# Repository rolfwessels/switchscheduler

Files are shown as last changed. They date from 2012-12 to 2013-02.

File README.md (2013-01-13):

Switch Scheduler
===============

Remotely schedule a switch to go on and off

The Idea
============
The idea is to have a web server host some scheduling setting. Then I would have an arduino with a wifly connected poll for new setting every 10 minutes. Based on the schedule I want to switch 1 or more switches on and off.

The story
==============
Initially I wanted this schedule to run for my geyser. Obviously a geyser pulls a lot of current and I was scared to tinker with a relay, so the plan was to switch it on and off using a servo and a little printed part. This would work on a normal switch but unfortunately this switch requires too much force for my servo. 

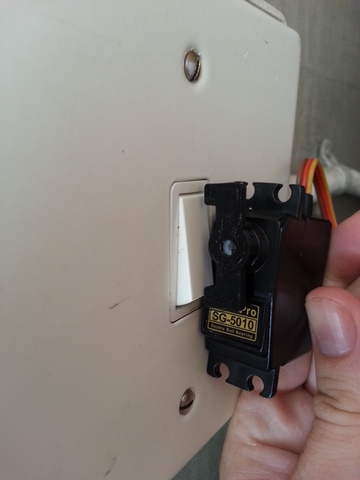
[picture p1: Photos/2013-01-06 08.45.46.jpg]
3d printed part to toggle the switch


Next would be to do it the right way using a relay. I went to my local electronic shop and picked up a hf18ff relay. It is a 12v relay and the arduino pins only push out 5v so I need to up the voltage somehow.

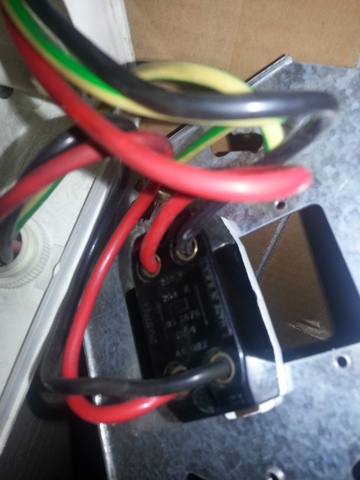
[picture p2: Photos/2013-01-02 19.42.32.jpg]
The back of the switch that will be hacked

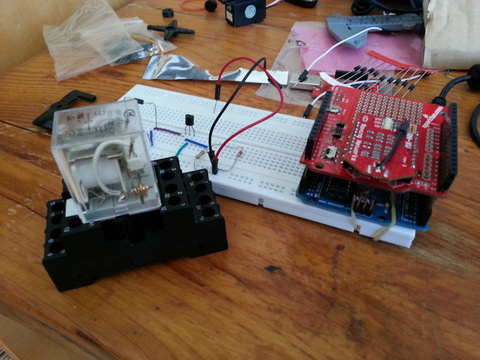
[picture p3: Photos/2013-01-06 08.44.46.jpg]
The relay and the wifly

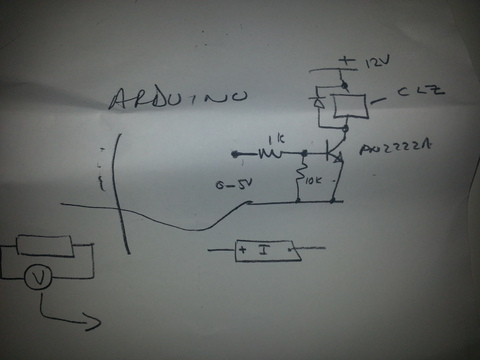
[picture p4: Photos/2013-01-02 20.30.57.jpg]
The suggested way of getting 5v to 12v


Missing bits
=============

- Develop the scheduling server
- Updating fritzing file
- Togle the 12v relay
- Installing the relay
- Create instructable
- Store schedule file on sd card for offline scheduling

Component list
===============

- arduino uno
- wifly
- wifly breakout board
- Relay [hf18ff]
- diode [1n4007]
- 1k resistor (R1)
- 10k resistor (R2)
- transistor [pn2222A]
- power supply (12V)

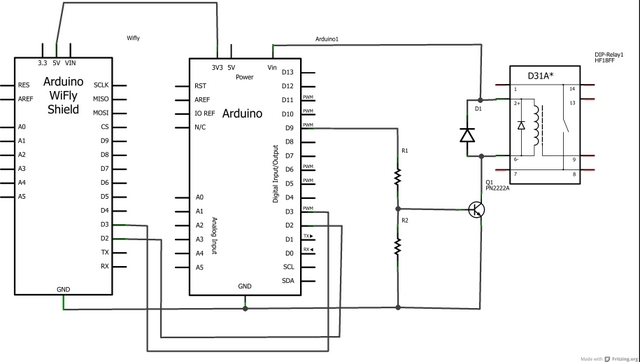
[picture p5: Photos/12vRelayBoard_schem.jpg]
The circuit


Required Arduino libraries
==============================

The schedular makes use of the following libraries. These libraries are included in the source code.
```AJson
NewSoftSerial
PString
SoftwareServo
Streaming
Time
TimeAlarms
WiFlySerial
```
All the arduino code is stored in folder ArduinoRemoteSwitch

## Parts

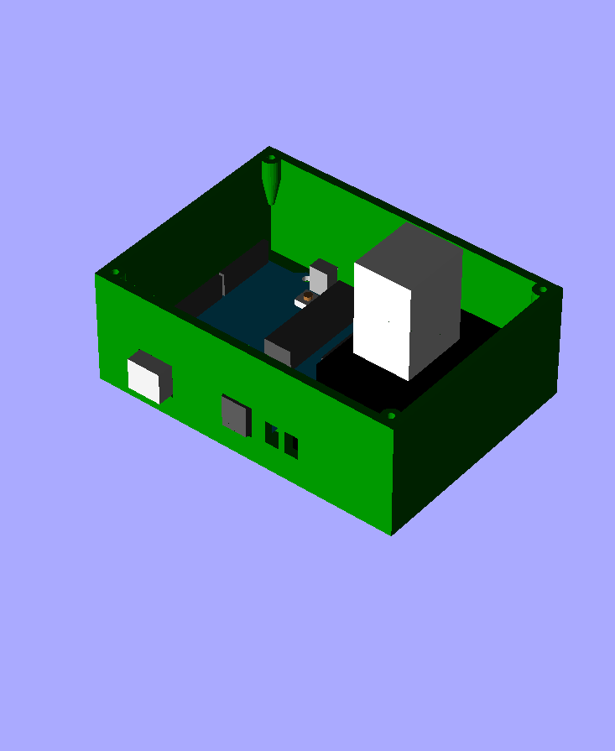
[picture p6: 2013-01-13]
Photos/boxWithComponents.png

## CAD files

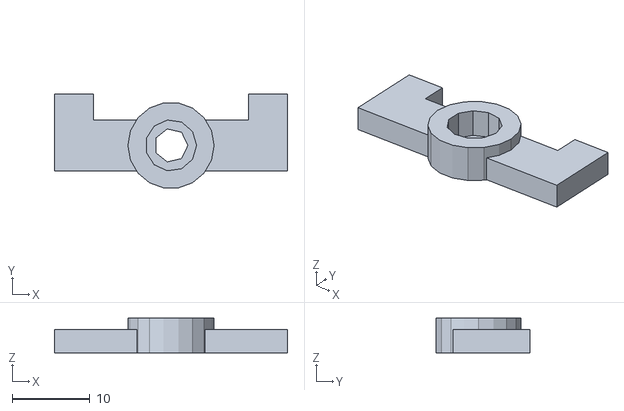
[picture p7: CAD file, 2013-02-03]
3dPrintedParts/ServoArm.stl
30.0 x 12.1 x 4.50

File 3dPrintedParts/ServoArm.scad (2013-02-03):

module cilinder()
{
	depth = 4.5;
	diameter = 3.2;
	dw = depth/2;
	dwI = dw/2;

	armDepth = depth/1.5;
	armHeigth = 18;
	armWidth = (diameter)*2;


	armGripsWidth = 5;
	armGripsHeigth = armWidth*1.5;

	difference() {
		union() {
			translate([-armHeigth/2,-armWidth/2,0])
     			cube([armHeigth,armWidth,armDepth]);
			translate([-armHeigth/2-armGripsWidth,-armWidth/2,0])
				cube([armGripsWidth,armGripsHeigth,armDepth]);
			translate([armHeigth/2,-armWidth/2,0])
				cube([armGripsWidth,armGripsHeigth,armDepth]);
			cylinder(depth,diameter+dw,diameter+dw);

			translate([-15,-armWidth/2,0])
				cube([armGripsWidth,armGripsHeigth,armDepth]);
			translate([+10,-armWidth/2,0])
				cube([armGripsWidth,armGripsHeigth,armDepth]);
		}
		translate([0,0,dwI])
			cylinder(depth,diameter,diameter);
		translate([0,0,-0.1])
		cylinder(depth,diameter-dwI,diameter-dwI);
	}
	
	
}

cilinder();

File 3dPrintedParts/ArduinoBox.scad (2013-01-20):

include<arduino.scad>

module Relay()
{
	width = 24;
	height = 20;
	depth = 33;
	color("white")		
		cube([width,height,depth]);
}

module RelayAndBase()
{
	width = 67;
	height = 30;
	depth = 20;
	level0w = 38;
	level0d = 4;
	level1w = 45;
	level1d = 10;
	screwRad = 2/2;
	
	union() {
		//the black bottom
		color("black")
		difference() {
			union() {
				cube([width,height,depth]);
				translate([(width-level1w)/2,0,depth])
					cube([level1w,height,level1d]);
				
			}
			//bottom gap
			translate([(width-level0w)/2,0,0])
					cube([level0w,height,level0d]);
			//screw holes
			translate([width/2,3,0])
				cylinder(r=screwRad, h=depth+level1d+1, $fn=25);
			translate([width/2,height-3,0])
				cylinder(r=screwRad, h=depth+level1d+1, $fn=25);

		}
		//the replay
		
		translate([(width-24)/2,5,depth+level1d])
			Relay();
	}
}

module OtherElements()
{
	translate(relayOffset)
		RelayAndBase();
	translate(arduinoOffset)
		Arduino(0, 0, 0);

}

module ScrewHolder() {
	arduinoRad = 1.2;
	outer = 2;
	depth = 7;
	difference() {
		cylinder(r=arduinoRad+outer, h=depth, $fn=25);
		cylinder(r=arduinoRad, h=depth+1, $fn=25);
	}
}

module BoxScrewHoldes()
{
	down = -1*arduinoOffsetY;
	left = 67/2;
	
		translate(relayOffset)
		union() {
			
			translate([left,13,0])
				ScrewHolder();
			translate([left,37,0])
				ScrewHolder();
		}
		
		//arduino
		translate(arduinoOffset) // from other elements
		union() {
			
			translate([-1,-38.4,down])
				ScrewHolder();
			translate([0,10,down])
				ScrewHolder();
			translate([51,-33.3,down])
				ScrewHolde();
			translate([51,-5.2,down])
				ScrewHolder();
			translate([51,-33.2,down])
				ScrewHolder();
			
		}
	
		
}
module ScrewHolderAndTaper() {
	
	depth = 7;
	mod = 1.5;
	union() {
		ScrewHolder();
		translate([0,0,-depth*mod])
		cylinder(r2=3.2, h=depth*mod, $fn=25);
		
	}
}

module BoxBottom()
{
	width = boxSize[0];
	height = boxSize[1];
	depth = boxSize[2];

	difference() {
		cube(boxSize);
		translate([boxWidth,boxWidth,boxWidth])
			cube([width-(boxWidth*2),height-(boxWidth*2),depth-boxWidth+10]);
		}
	offset = boxWidth+1.2;
	depthSc = depth-7;
	translate([offset,offset,depthSc])
		ScrewHolderAndTaper();
	translate([width-offset,offset,depthSc])
		ScrewHolderAndTaper();
	translate([offset,height-offset,depthSc])
		ScrewHolderAndTaper();
	translate([width-offset,height-offset,depthSc])
		ScrewHolderAndTaper();
	
}

module PowerHoles()
{
	translate(arduinoOffset) // from other elements
	union() {
		//usb
		translate([-23,-9,3]) cube([15,13,12]);
		//power
		translate([-23,-39,4]) cube([15,11,11]);

		//power
		translate([-23,-39,4]) cube([15,8,11]);
	}
	powercableHole = [15,5,8];		
	translate(relayOffset)
	union() {
		//power
		translate([-10,41,10]) cube(powercableHole);
		translate([-10,34,10]) cube(powercableHole);
	}
	
}
module BoxTopScrewHoles()
{
	width = boxSize[0];
	height = boxSize[1];
	depth = 0;

	offset = boxWidth+1.2;
	depthSc = depth;
	myheight = boxWidth*2;
	mod = 1;

	translate([offset,offset,depthSc])
		cylinder(r=1.2, h=myheight, $fn=25);
	translate([width-offset,offset,depthSc])
		cylinder(r=1.2, h=myheight, $fn=25);
	translate([offset,height-offset,depthSc])
		cylinder(r=1.2, h=myheight, $fn=25);
	translate([width-offset,height-offset,depthSc])
		cylinder(r=1.2, h=myheight, $fn=25);
}
module BoxTop()
{
	width = boxSize[0];
	height = boxSize[1];
	depth = 0;
	difference() {
		translate([0,0,depth])
			cube([width,height,boxWidth]);
		translate([26,14,depth])
			cube([26,23,33]);
		BoxTopScrewHoles();
	}
	
	
}


module Box() {
	depth = boxSize[2];
	color("green") BoxScrewHoldes();
	difference() {
		color("green") BoxBottom();
		color("green") PowerHoles();
	}
	translate([0,0,depth+1]) color("lightgreen") BoxTop();

}

module FullBoxWithComponents() {
	translate([0,10,2]) OtherElements();
	Box();
}

module BoxBottomOnly() {
	color("green") BoxScrewHoldes();
	difference() {
		color("green") BoxBottom();
		color("green") PowerHoles();
	}
}

module TopOnly() {
	 color("lightgreen") BoxTop();
}

//Main settings
relayOffset = [5,0,0];
arduinoOffsetY = 5;
arduinoOffset = [16,90,arduinoOffsetY];
boxSize = [80,110,40];
boxWidth = 2;

// Preview
FullBoxWithComponents();

// Print 1
// BoxBottomOnly();

// Print 2
// TopOnly();

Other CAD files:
3dPrintedParts/arduino.scad
3dPrintedParts/ServoArm.skp

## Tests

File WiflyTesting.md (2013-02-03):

How to test your wifly connection using USB
==================================================
Connect to the wifly to USD
Telnet to the wifly:
Send commands:

```
$$$  //Responds with CMD
scan 30 // scans for networks
join # 3        // Join the third network

// Below sets the auth to | WPA1 | channel 11 | password XXXXXXX | join on connection | ssid | joins pings and saves connection
set wlan auth 3
set wlan channel 11 
set wlan pass XXXXXXX  

set wlan join 1
set wlan ssid CC902
join CC902
ping 74.125.233.5 2
save
reboot

set time address 129.6.15.28 
set time zone 22
set time enable 1 
time
show time
save
reboot
```

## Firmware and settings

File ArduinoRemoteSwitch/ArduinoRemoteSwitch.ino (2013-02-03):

#include <Arduino.h> 
#include <Time.h>
#include <SoftwareSerial.h>
#include <Streaming.h>
#include <PString.h>
#include <WiFlySerial.h>
#include <String.h>
#include "MemoryFree.h"
#include "Credentials.h"

#define REQUEST_BUFFER_SIZE 150
#define HTTP_RESPONSE_BUFFER_SIZE 200

#define DAYS 7
#define SCHEDULEBLOCKS 24
#define HOURFALSE 255
//time in minutes
#define SHEDULE_DOWNLOAD_SCHEDULE 10
//time in seconds
#define SHEDULE_CHECK_SCHEDULE 5 
//time in hours
#define SHEDULE_SETTIME 2

#define SettingsFullUrl "https://dl.dropbox.com/u/1343111/ServerTimer/autoSwitchSettings.txt"
#define SETTINGS_HOST "dl.dropbox.com"
//#define SETTINGS_HOST "23.21.195.136"
#define SettingsUrl "/u/1343111/ServerTimer/autoSwitchSettings.txt"


char bufRequest[REQUEST_BUFFER_SIZE];
char bufResponse[HTTP_RESPONSE_BUFFER_SIZE];

bool _daysSchedule[DAYS*SCHEDULEBLOCKS] = {false};
bool _servoState = false;
byte _onHour = HOURFALSE;
String _mac; 

bool isFirstRun = true;
int pinLed = 5;
int pinRelay = 4;
// Arduino       _wiflySerial
//  2 - receive  TX   (Send from _wiflySerial, Receive to Arduino)
//  3 - send     RX   (Send from Arduino, Receive to _wiflySerial) 
WiFlySerial _wiflySerial(2,3); 
char chOut; 


// the setup routine runs once when you press reset:
void setup() {
	Serial.begin(9600);
	pinMode(pinLed, OUTPUT);
	pinMode(pinRelay, OUTPUT);
	switchRelay(false);
	Serial << "--------------------------------------------- " <<  F("Free memory:") << freeMemory() << endl;
}


// the loop routine runs over and over again forever:
void loop() {
  while(_wiflySerial.available() > 0) {
    Serial.write(_wiflySerial.read());
  }  
  if(Serial.available()) { // Outgoing data
    _wiflySerial.write( (chOut = Serial.read()) );
    Serial.write (chOut);
  }

  // download a schedule every 15 minutes
  if (isFirstRun || ((minute() % SHEDULE_DOWNLOAD_SCHEDULE == 0) && (second() == 0) )) {
                if (isFirstRun) fullSetup();		
                connectToWiFly();
                
		if (isFirstRun || ( (hour() % SHEDULE_SETTIME == 0) && (minute() == 0)) ) {
			setNTPAndSetTheCurrentTime();
		}
		downloadNewSchedule();
  }

  // check the schedule every 5 seconds
  if (isFirstRun || ((second() % SHEDULE_CHECK_SCHEDULE == 0))) {
	  checkScheduleAndUpdateSwitch();
	  
  }
  
  delay(1000);
} 


void downloadNewSchedule() {
	Serial << "downloadNewSchedule " <<  F("Free memory:") << freeMemory() << endl;
	char* page = getHttp(SETTINGS_HOST,SettingsUrl);
	parseSchedule(page);
	checkSchedule();
	checkScheduleAndUpdateSwitch();
}

void switchRelay(bool value) {
	if (_servoState != value) {
		_servoState = value;
		
		if (_servoState) {
			digitalWrite(pinLed, HIGH);
			digitalWrite(pinRelay, HIGH);
		}
		else {
			digitalWrite(pinLed, LOW);
			digitalWrite(pinRelay, HIGH);
			// reset the on hour value so that it does not repeat daily
			_onHour = HOURFALSE;
		}
		Serial << "Relay is now " << _servoState << endl;
	}
}

void checkScheduleAndUpdateSwitch() {
  bool isCurrentlyOn = _onHour == hour() || getSchedule(weekday()-1,hour());
  Serial << "Day:" <<weekday()-1 << "[" << weekday()-1 << "] Hour:" << hour() << ":" << minute() << ":" << second()  << " IsOn:" << isCurrentlyOn  << endl;
  switchRelay(isCurrentlyOn);
}

void checkSchedule() {
	Serial << "checkSchedule " <<  F("Free memory:") << freeMemory() << endl;
	bool hOn;
	for (byte day = 0; day < DAYS ; day++) {
		for (byte hour = 0; hour < SCHEDULEBLOCKS ; hour++) {
			hOn = getSchedule(day,hour);
			if (hOn) {
				Serial << "Day:" << day  << " Hour:" << hour << " On:" << hOn << endl;
			}
		}	
	}
}

void parseSchedule(char* scheduleString) {
	Serial << "parseSchedule " <<  F("Free memory:") << freeMemory() << endl;
	//Serial << "---" << scheduleString << "---" << endl;
	byte pointer = 0; // ship first char
	if (scheduleString[pointer++] != '{') {
		Serial << "Invalid scheduleString" << endl;
		return;
	}
	isFirstRun = false;
	bool hOn;
	if (parseScheduleChar(scheduleString,pointer++)) {
		_onHour =  hour();
		Serial << "Enable the switch for hour of :" << _onHour << endl;
	}
	else {
		_onHour =  HOURFALSE;
	}
	
	for (byte day = 0; day < DAYS ; day++) {
		for (byte hour = 0; hour < SCHEDULEBLOCKS ; hour++) {
			hOn = parseScheduleChar(scheduleString,pointer++);
			//if (hOn) { Serial << "Day:" << day  << " Hour:" << hour << " On:" << hOn << endl; }
			putSchedule(day, hour ,hOn);
		}	
	}
}


bool parseScheduleChar(char* scheduleString,byte pointer) {
	return scheduleString[pointer] == '1';
}

void putSchedule(byte day, byte hour ,bool value) {
	byte pos = ((day) * SCHEDULEBLOCKS)  + hour;
	//Serial << "putSchedule " << day << " " << hour << " " << value << " " << pos << endl;
	_daysSchedule[pos]  = value;
}

bool getSchedule(byte day, byte hour ) {
	byte pos = ((day) * SCHEDULEBLOCKS)  + hour;
	return _daysSchedule[pos];
}

void connectToWiFly() {
	Serial << "connectToWiFly " <<  F("Free memory:") << freeMemory() << endl;
	_wiflySerial.begin();
	_mac = String(_wiflySerial.getMAC(bufRequest, REQUEST_BUFFER_SIZE)) ;
	Serial << F("Starting _wiflySerial ") <<  _wiflySerial.getLibraryVersion(bufRequest, REQUEST_BUFFER_SIZE) << " on " << _mac  << endl;
	
	joinWiflyIfNotUp();
	
	setWelcomeText();
	_wiflySerial.closeConnection();
  
	// clear out prior requests.
	clearOutPriorRequests();
}
void fullSetup() {
	Serial << "Leave:" <<  ssid << _wiflySerial.leave() << endl;
	_wiflySerial.setAuthMode( WIFLY_AUTH_WPA2_PSK);
	_wiflySerial.setJoinMode( WIFLY_JOIN_AUTO );
	_wiflySerial.setChannel("11");
	_wiflySerial.setDHCPMode( WIFLY_DHCP_ON );
	// join
	if (_wiflySerial.setSSID(ssid) ) {    
		Serial << "SSID Set :" << ssid << endl;
	}
	if (_wiflySerial.setPassphrase(passphrase)) {
		Serial << "Passphrase Set :" << passphrase << endl;
	}
}

void joinWiflyIfNotUp() {
	_wiflySerial.getDeviceStatus();
	if (!_wiflySerial.isifUp()) 
	{
		Serial << "Joining... :"<< ssid << endl;
		if ( _wiflySerial.join() ) 
		{
			Serial << F("Joined ") << ssid << F(" successfully.") << endl;
		} 
		else 
		{
			Serial << F("Join to ") << ssid << F(" failed.") << endl;
		}
	}
	else {
		Serial << "Connection is up... :"<< ssid << endl;
		getConnectionInfo();
	}
	
}

void  setNTPAndSetTheCurrentTime() {
  Serial << "setNTPAndSetTheCurrentTime " << ntp_server <<  F(" Free memory:") << freeMemory() << endl;
  
  _wiflySerial.setNTP(ntp_server); 
  _wiflySerial.setNTP_Update_Frequency("1");
  _wiflySerial.setNTP_UTC_Offset(2);
  _wiflySerial.SendCommand("time",">", bufResponse, HTTP_RESPONSE_BUFFER_SIZE);
  setTime(_wiflySerial.getTime());
  Serial << F("DateTime: ") << year() << "-" << month() << "-" << day() << " " << _DEC(hour()) << ":" << minute() << ":" << second() << endl;
  setSyncProvider( getSyncProvider );
  getSyncProvider();
  _wiflySerial.exitCommandMode();
}

time_t getSyncProvider() {
  time_t tCurrent = (time_t) _wiflySerial.getTime();
  return tCurrent;
}

void setWelcomeText() {
	//Set the welcom string to ""
	_wiflySerial.SendCommand("set comm remote 0",">", bufResponse, HTTP_RESPONSE_BUFFER_SIZE);
	memset(bufResponse,'\0',HTTP_RESPONSE_BUFFER_SIZE);
}

void clearOutPriorRequests() {
	
	_wiflySerial.flush();
	while (_wiflySerial.available() )
	_wiflySerial.read();
}

char* getHttp(char* host, char* url) {
  
  PString strRequest(bufRequest, REQUEST_BUFFER_SIZE);
  PString response(bufResponse, HTTP_RESPONSE_BUFFER_SIZE);

  strRequest << F("GET ") << url << "?mac=" <<  _mac;
  
  Serial << F("GET request: http://") << host << strRequest << F(" Free memory:") << freeMemory() << endl;
  // Build GET expression
  strRequest << F(" HTTP/1.1") << "\n"
     << F("Host: ") <<  host << "\n"
     << F("Connection: close") << "\n"
     << "\n\n";
  
  // Open connection, then sent GET Request, and display response.
  if (_wiflySerial.openConnection( host ) ) {
    
    _wiflySerial <<  (const char*) strRequest << endl; 
    
    // Show server response
    unsigned long TimeOut = millis() + 30000;

    char currentChar = '2';
    int counter = 0;
    boolean headerDone = false;
    while (  TimeOut > millis() && _wiflySerial.isConnectionOpen() ) {
      if (  _wiflySerial.available() > 0 ) {
		 currentChar = _wiflySerial.read();
		 headerDone = (headerDone || currentChar == '{') && currentChar != '}'; 
         if (headerDone) {
            response.write(currentChar);
			counter++;
         }
      }
	}
    if (TimeOut < millis()) {
      Serial << F("Timed out!") << host << endl;
    }
	Serial << "Done loading from " << host << " bytes read:"<< counter << " into buffer " << HTTP_RESPONSE_BUFFER_SIZE << endl; 
	_wiflySerial.closeConnection();
  }
  else 
  {
    // Failed to open connection
    Serial << F("Failed to connect to:") << host << endl;
  }  
  _wiflySerial.setDebugChannel( NULL );
  return bufResponse;
}
void getConnectionInfo() {
	Serial << 
		F("IP: ") << _wiflySerial.getIP(bufRequest, REQUEST_BUFFER_SIZE) << endl <<
		F("Netmask: ") << _wiflySerial.getNetMask(bufRequest, REQUEST_BUFFER_SIZE) << endl <<
		F("Gateway: ") << _wiflySerial.getGateway(bufRequest, REQUEST_BUFFER_SIZE) << endl <<
		F("DNS: ") << _wiflySerial.getDNS(bufRequest, REQUEST_BUFFER_SIZE) << endl  /*<<
		F("_wiflySerial Sensors: ") << bufBody <<  _wiflySerial.SendCommand("show q 0x177 ",">", bufBody, BODY_BUFFER_SIZE) << endl << 
		F("_wiflySerial Temp: ") <<  _wiflySerial.SendCommand("show q t ",">", bufBody, BODY_BUFFER_SIZE) << endl  << 
		F("_wiflySerial battery: ") << _wiflySerial.getBattery(bufBody, BODY_BUFFER_SIZE) << endl*/
		;
}

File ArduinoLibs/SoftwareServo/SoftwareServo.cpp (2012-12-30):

#include <SoftwareServo.h>
#include <Arduino.h>

SoftwareServo *SoftwareServo::first;

#define NO_ANGLE (0xff)

SoftwareServo::SoftwareServo() : pin(0),angle(NO_ANGLE),pulse0(0),min16(34),max16(150),next(0)
{}

void SoftwareServo::setMinimumPulse(uint16_t t)
{
    min16 = t/16;
}

void SoftwareServo::setMaximumPulse(uint16_t t)
{
    max16 = t/16;
}

uint8_t SoftwareServo::attach(int pinArg)
{
    pin = pinArg;
    angle = NO_ANGLE;
    pulse0 = 0;
    next = first;
    first = this;
    digitalWrite(pin,0);
    pinMode(pin,OUTPUT);
    return 1;
}

void SoftwareServo::detach()
{
    for ( SoftwareServo **p = &first; *p != 0; p = &((*p)->next) ) {
	if ( *p == this) {
	    *p = this->next;
	    this->next = 0;
	    return;
	}
    }
}

void SoftwareServo::write(int angleArg)
{
    if ( angleArg < 0) angleArg = 0;
    if ( angleArg > 180) angleArg = 180;
    angle = angleArg;
    // bleh, have to use longs to prevent overflow, could be tricky if always a 16MHz clock, but not true
    // That 64L on the end is the TCNT0 prescaler, it will need to change if the clock's prescaler changes,
    // but then there will likely be an overflow problem, so it will have to be handled by a human.
    pulse0 = (min16*16L*clockCyclesPerMicrosecond() + (max16-min16)*(16L*clockCyclesPerMicrosecond())*angle/180L)/64L;
}

uint8_t SoftwareServo::read()
{
    return angle;
}

uint8_t SoftwareServo::attached()
{
    for ( SoftwareServo *p = first; p != 0; p = p->next ) {
	if ( p == this) return 1;
    }
    return 0;
}

void SoftwareServo::refresh()
{
    uint8_t count = 0, i = 0;
    uint16_t base = 0;
    SoftwareServo *p;
    static unsigned long lastRefresh = 0;
    unsigned long m = millis();

    // if we haven't wrapped millis, and 20ms have not passed, then don't do anything
    if ( m >= lastRefresh && m < lastRefresh + 20) return;
    lastRefresh = m;

    for ( p = first; p != 0; p = p->next ) if ( p->pulse0) count++;
    if ( count == 0) return;

    // gather all the SoftwareServos in an array
    SoftwareServo *s[count];
    for ( p = first; p != 0; p = p->next ) if ( p->pulse0) s[i++] = p;

    // bubblesort the SoftwareServos by pulse time, ascending order
    for(;;) {
	uint8_t moved = 0;
	for ( i = 1; i < count; i++) {
	    if ( s[i]->pulse0 < s[i-1]->pulse0) {
		SoftwareServo *t = s[i];
		s[i] = s[i-1];
		s[i-1] = t;
		moved = 1;
	    }
	}
	if ( !moved) break;
    }

    // turn on all the pins
    // Note the timing error here... when you have many SoftwareServos going, the
    // ones at the front will get a pulse that is a few microseconds too long.
    // Figure about 4uS/SoftwareServo after them. This could be compensated, but I feel
    // it is within the margin of error of software SoftwareServos that could catch
    // an extra interrupt handler at any time.
    for ( i = 0; i < count; i++) digitalWrite( s[i]->pin, 1);

    uint8_t start = TCNT0;
    uint8_t now = start;
    uint8_t last = now;

    // Now wait for each pin's time in turn..
    for ( i = 0; i < count; i++) {
	uint16_t go = start + s[i]->pulse0;

	// loop until we reach or pass 'go' time
	for (;;) {
	    now = TCNT0;
	    if ( now < last) base += 256;
	    last = now;

	    if ( base+now > go) {
		digitalWrite( s[i]->pin,0);
		break;
	    }
	}
    }
}

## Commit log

2012-12-30 Connection works but we have a memory issue
    [ArduinoRemoteSwitch.ino]
2012-12-30 Working with LED
2012-12-30 Adding servo makes it go crazy
2012-12-30 SoftwareServo works better than internal servo program
2012-12-30 Adding the servo arm. For printing
    [ServoArm.scad, ServoArm.skp, ServoArm.stl]
2013-01-06 Adding scad file, Adding the fritzing bread board layout
    [12vRelayBoard.fzz, ServoArm.scad]
2013-01-07 Update relay board Update the arduino to load time on start
    [12vRelayBoard.fzz]
2013-01-07 Replace servo with relay
    [ArduinoRemoteSwitch.ino]
2013-01-08 Adding some circuits
    [12vRelayBoard.fzz]
2013-01-13 Found issue with my bread board
    [ArduinoRemoteSwitch.ino]
2013-01-13 Adding box to house the components
    [12vRelayBoard.fzz, ArduinoBox.scad, arduino.scad]
2013-01-13 Adding schedule-service
    [ArduinoBox.scad]
2013-01-20 Adding the clojure project that is currently working
2013-01-20 Split scad
    [ArduinoBox.scad]
2013-02-03 Updates before adding new mvc.net webservice
    [ServoArm.scad, ServoArm.stl]
